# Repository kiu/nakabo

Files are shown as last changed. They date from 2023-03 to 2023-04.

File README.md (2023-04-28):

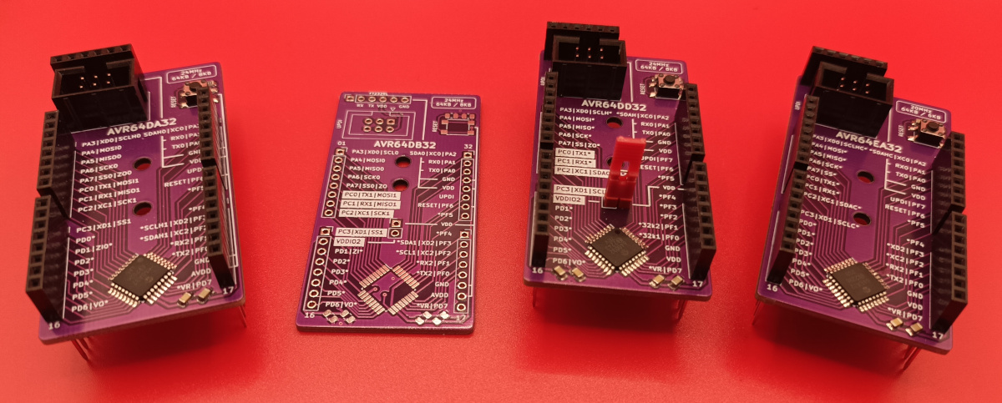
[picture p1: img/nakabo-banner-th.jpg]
nakabo-banner


# nakabo

Welcome to *nakabo* - a collection of neatly designed breakout boards aimed at simplifying development and experimentation.

Feel free to give me a shoutout [@kiu112](https://twitter.com/kiu112) - I would love to see how my [#nakabo](https://twitter.com/search?q=%2523nakabo) boards are being used in your projects.

# nakabo-avr64*

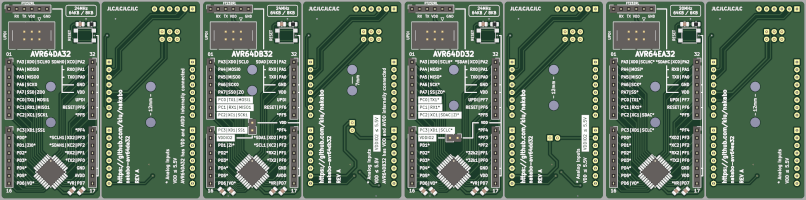
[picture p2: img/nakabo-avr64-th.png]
nakabo-avr64


* All pins routed out to headers / sockets
* AVR6 IDC connector (6P 2x03 2.54mm / 100mil) for UPDI programming and debugging
* Major pin functions documented on front silkscreen
* 2.54mm / 100mil breadboard compatible spacing
* Dedicated reset button
* [FT232RL module](https://www.amazon.de/s?k=FT232RL+module) compatible pin socket for easy serial interfacing

Disclaimer: These are not plug and play development boards - you need an UPDI compatible programmer to use them. There is no protection (e.g. reverse polarity), handle with care.

## nakabo-avr64da32

*nakabo-avr64da32* is a break-out board for the [AVR64DA32](https://www.microchip.com/en-us/product/AVR64DA32) microcontroller.

(Hint: stencil is identical to *nakabo-avr64ea32*)

## nakabo-avr64db32

*nakabo-avr64db32* is a break-out board for the [AVR64DB32](https://www.microchip.com/en-us/product/AVR64DB32) microcontroller.

(Hint: stencil is identical to *nakabo-avr64dd32*)

## nakabo-avr64dd32

*nakabo-avr64dd32* is a break-out board for the [AVR64DD32](https://www.microchip.com/en-us/product/AVR64DD32) microcontroller.

(Hint: stencil is identical to *nakabo-avr64db32*)

## nakabo-avr64ea32

*nakabo-avr64ea32* is a break-out board for the [AVR64EA32](https://www.microchip.com/en-us/product/AVR64EA32) microcontroller.

(Hint: stencil is identical to *nakabo-avr64da32*)

# License

This project is licensed under the Creative Commons Attribution-NonCommercial 3.0 Unported (CC BY-NC 3.0) license.

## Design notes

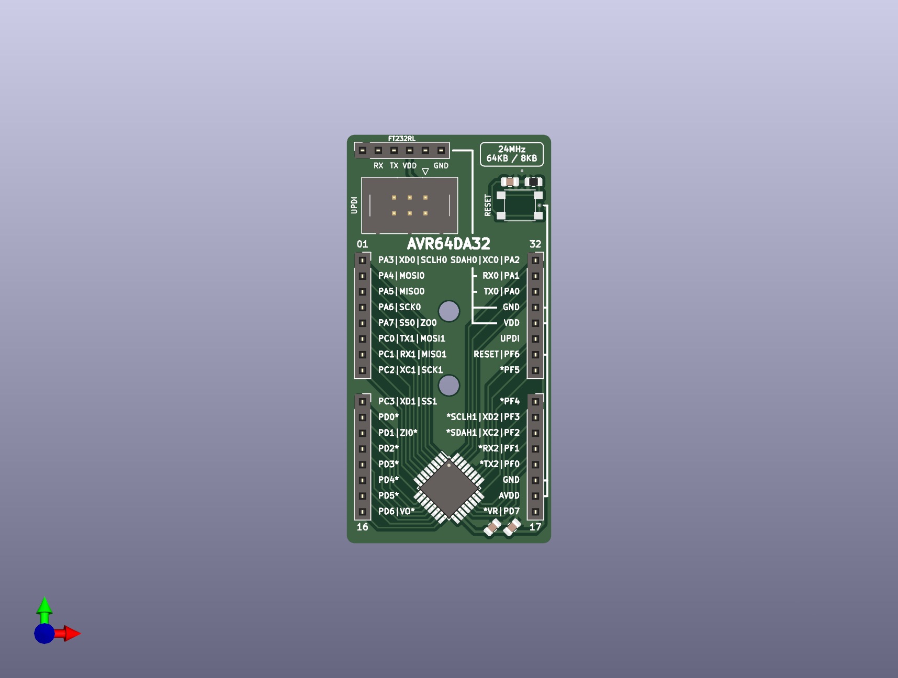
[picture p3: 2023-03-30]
nakabo-avr64da32/nakabo-avr64da32-render-F.png

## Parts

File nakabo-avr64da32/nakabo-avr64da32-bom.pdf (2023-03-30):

BOM

Page 1

Symbol | Description | Req | +VAT | Price | Price (sum) | Provider | ID
| | | | MOQ 10
U1 | AVR64DA32 | 1 | 19 | 1,90 € | 2,26 € | www.mouser.de | 579-AVR64DA32-I/PT
C1 | 10nF 0805 | 1 | 0 | 0,00 € | 0,00 € | www.lcsc.com | C465162
C2, C3 | 100nF 0805 | 2 | 0 | 0,00 € | 0,01 € | www.lcsc.com | C2830721
R1 | 330R 0805 | 1 | 0 | 0,00 € | 0,00 € | www.lcsc.com | C2930274
SW1 | Switch 4.5mmx4.5mm | 1 | 0 | 0,01 € | 0,01 € | www.lcsc.com | C2888502
J1, J2, J3, J4 | 1x08 2.54 THT (8p 15mm) | 4 | 0 | 0,35 € | 1,39 € | www.aliexpress.com | 32891220095
J5 | IDC Socket 2x03 2.54 THT | 1 | 0 | 0,14 € | 0,06 € | www.lcsc.com | C2833845
J6 | PinSocket 1x06 2.54 THT | 1 | 0 | 0,06 € | 0,06 € | www.lcsc.com | C2935900
- | PCB 66.04 x 30.02 + Stencil + Shipping | 1 | 0 | 2,73 € | 2,73 € | -

SUM
6,52 €
65,21 €

www.jlcpcb.com

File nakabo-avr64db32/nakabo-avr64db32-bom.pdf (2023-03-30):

BOM

Page 1

Symbol | Description | Req | +VAT | Price | Price (sum) | Provider | ID
| | | | MOQ 10
U1 | AVR64DB32 (single quantity not available) | 1 | 19 | 1,82 € | 2,17 € | www.mouser.de | 579-AVR64DB32-I/PT
C1, C3 | 100nF 0805 | 2 | 0 | 0,00 € | 0,01 € | www.lcsc.com | C2830721
C2, C4, C5 | 1uF 0805 | 3 | 0 | 0,01 € | 0,02 € | www.lcsc.com | C2837735
R1 | 330R 0805 | 1 | 0 | 0,00 € | 0,00 € | www.lcsc.com | C2930274
SW1 | Switch 4.5mmx4.5mm | 1 | 0 | 0,01 € | 0,01 € | www.lcsc.com | C2888502
J1, J2, J3, J4 | 1x08 2.54 THT (8p 15mm) | 4 | 0 | 0,35 € | 1,39 € | www.aliexpress.com | 32891220095
J5 | IDC Socket 2x03 2.54 THT | 1 | 0 | 0,14 € | 0,06 € | www.lcsc.com | C2833845
J6 | PinSocket 1x06 2.54 THT | 1 | 0 | 0,06 € | 0,06 € | www.lcsc.com | C2935900
J7 | PinHeader 1x02 2.54 THT | 1 | 0 | 0,01 € | 0,01 € | www.lcsc.com | C2935908
- | Jumper | 1 | 0 | 0,02 € | 0,02 € | www.lcsc.com | C5274548
- | PCB 66.04 x 30.02 + Stencil + Shipping | 1 | 0 | 2,73 € | 2,73 € | -

SUM
6,47 €
64,72 €

www.jlcpcb.com

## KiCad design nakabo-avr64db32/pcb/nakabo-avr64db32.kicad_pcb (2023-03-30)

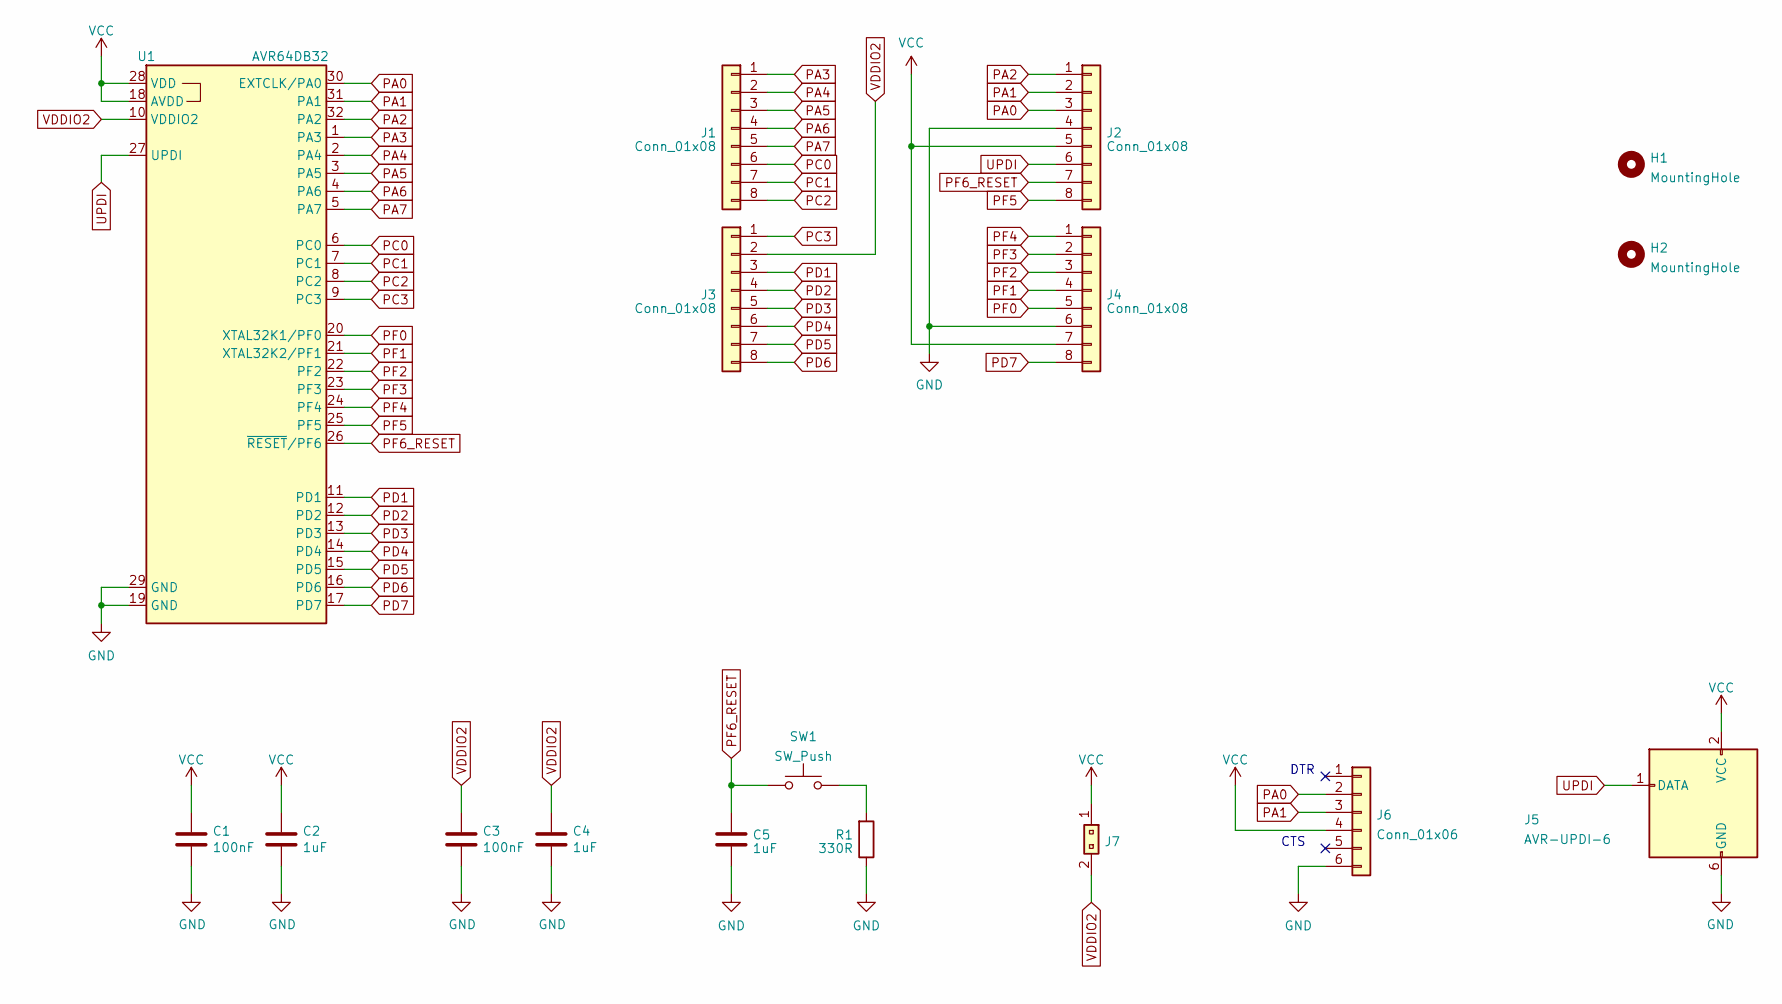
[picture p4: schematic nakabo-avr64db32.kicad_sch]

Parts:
C1, C3: 100nF; C_0805_2012Metric
C2, C4, C5: 1uF; C_0805_2012Metric
H1, H2: MountingHole; MountingHole_3.2mm_M3_DIN965
J1, J2, J3, J4: Conn_01x08; PinSocket_1x08_P2.54mm_Vertical
J5: AVR-UPDI-6; IDC-Header_2x03_P2.54mm_Vertical
J6: Conn_01x06; PinSocket_1x06_P2.54mm_Vertical
J7: 1x02_Jumper; PinHeader_1x02_P2.54mm_Vertical
R1: 330R; R_0805_2012Metric
SW1: SW_Push; SW_Push_1P1T_NO_4.5x4.5mm
U1: AVR64DB32; TQFP-32_7x7mm_P0.8mm

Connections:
GND: C1.2, C2.2, C3.2, C4.2, C5.2, J2.4, J4.6, J5.6 (GND), J6.6, R1.1, U1.19 (GND), U1.29 (GND)
unnamed: R1.2, SW1.2
PA0: J2.3, J6.2, U1.30 (EXTCLK/PA0)
PA1: J2.2, J6.3, U1.31 (PA1)
PA2: J2.1, U1.32 (PA2)
PA3: J1.1, U1.1 (PA3)
PA4: J1.2, U1.2 (PA4)
PA5: J1.3, U1.3 (PA5)
PA6: J1.4, U1.4 (PA6)
PA7: J1.5, U1.5 (PA7)
PC0: J1.6, U1.6 (PC0)
PC1: J1.7, U1.7 (PC1)
PC2: J1.8, U1.8 (PC2)
PC3: J3.1, U1.9 (PC3)
PD1: J3.3, U1.11 (PD1)
PD2: J3.4, U1.12 (PD2)
PD3: J3.5, U1.13 (PD3)
PD4: J3.6, U1.14 (PD4)
PD5: J3.7, U1.15 (PD5)
PD6: J3.8, U1.16 (PD6)
PD7: J4.8, U1.17 (PD7)
PF0: J4.5, U1.20 (XTAL32K1/PF0)
PF1: J4.4, U1.21 (XTAL32K2/PF1)
PF2: J4.3, U1.22 (PF2)
PF3: J4.2, U1.23 (PF3)
PF4: J4.1, U1.24 (PF4)
PF5: J2.8, U1.25 (PF5)
PF6_RESET: C5.1, J2.7, SW1.1, U1.26 (~RESET/PF6)
UPDI: J2.6, J5.1 (DATA), U1.27 (UPDI)
VCC: C1.1, C2.1, J2.5, J4.7, J5.2 (VCC), J6.4, J7.1, U1.18 (AVDD), U1.28 (VDD)
VDDIO2: C3.1, C4.1, J3.2, J7.2, U1.10 (VDDIO2)

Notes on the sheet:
DTR
CTS

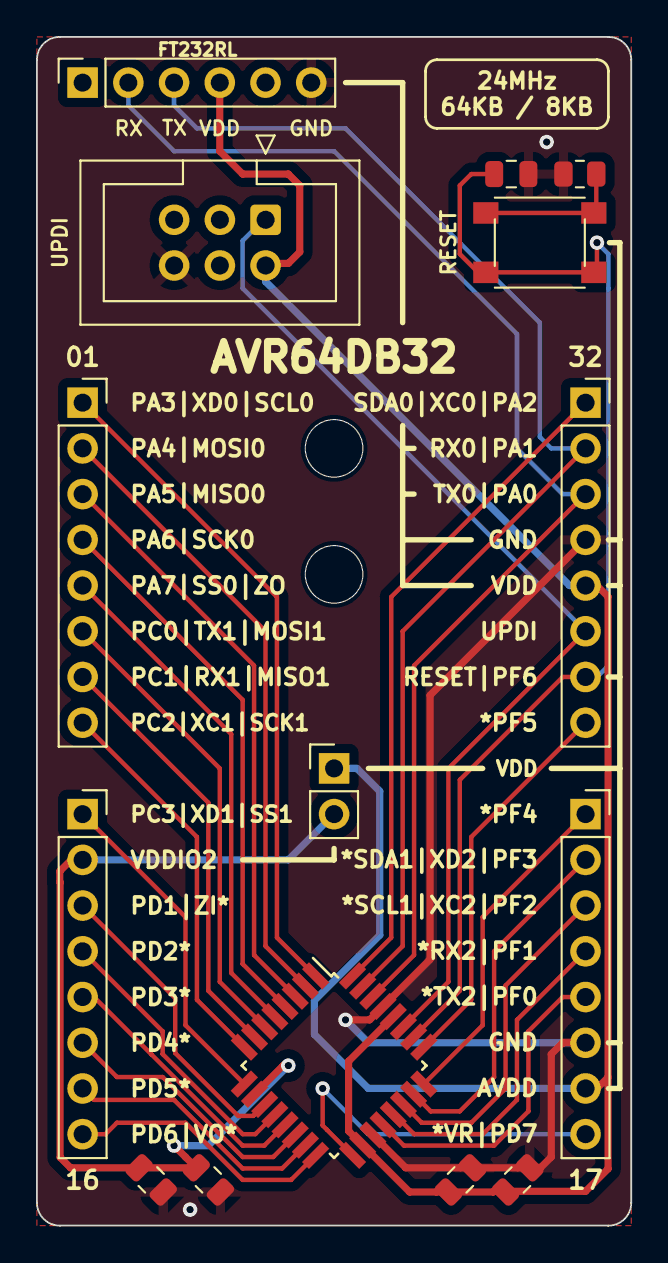
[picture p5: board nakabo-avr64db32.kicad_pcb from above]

Board: 2 copper layers, 33.0 x 66.0 mm, 17 parts (0 on the bottom side), 31 nets.

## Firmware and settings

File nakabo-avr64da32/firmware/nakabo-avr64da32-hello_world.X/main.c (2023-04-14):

/*
 * MAIN Generated Driver File
 * 
 * @file main.c
 * 
 * @defgroup main MAIN
 * 
 * @brief This is the generated driver implementation file for the MAIN driver.
 *
 * @version MAIN Driver Version 1.0.0
 */

/*
� [2023] Microchip Technology Inc. and its subsidiaries.

    Subject to your compliance with these terms, you may use Microchip 
    software and any derivatives exclusively with Microchip products. 
    You are responsible for complying with 3rd party license terms  
    applicable to your use of 3rd party software (including open source  
    software) that may accompany Microchip software. SOFTWARE IS ?AS IS.? 
    NO WARRANTIES, WHETHER EXPRESS, IMPLIED OR STATUTORY, APPLY TO THIS 
    SOFTWARE, INCLUDING ANY IMPLIED WARRANTIES OF NON-INFRINGEMENT,  
    MERCHANTABILITY, OR FITNESS FOR A PARTICULAR PURPOSE. IN NO EVENT 
    WILL MICROCHIP BE LIABLE FOR ANY INDIRECT, SPECIAL, PUNITIVE, 
    INCIDENTAL OR CONSEQUENTIAL LOSS, DAMAGE, COST OR EXPENSE OF ANY 
    KIND WHATSOEVER RELATED TO THE SOFTWARE, HOWEVER CAUSED, EVEN IF 
    MICROCHIP HAS BEEN ADVISED OF THE POSSIBILITY OR THE DAMAGES ARE 
    FORESEEABLE. TO THE FULLEST EXTENT ALLOWED BY LAW, MICROCHIP?S 
    TOTAL LIABILITY ON ALL CLAIMS RELATED TO THE SOFTWARE WILL NOT 
    EXCEED AMOUNT OF FEES, IF ANY, YOU PAID DIRECTLY TO MICROCHIP FOR 
    THIS SOFTWARE.
 */
#include "mcc_generated_files/system/system.h"
#include "mcc_generated_files/timer/delay.h"

/*
    Main application
 */

int main(void) {
    SYSTEM_Initialize();

    printf("https://github.com/kiu/nakabo\n");
    printf("nakabo-avr64da32 REV A\n");
    printf("\n");
    while (1) {
        printf("Hello World!\n");
        IO_PC0_Toggle();
        DELAY_milliseconds(1000);
    }
}
